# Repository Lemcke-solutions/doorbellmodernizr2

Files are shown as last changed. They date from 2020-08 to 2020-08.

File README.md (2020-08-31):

Imgur

This repository contains sample code and eagle/gerber/STL files for the Doorbell Modernizr 2 that is for sale on tindie: https://www.tindie.com/products/ErikLemcke/doorbell-modernizr-2/

The Doorbell Modernizr is a device that can transform your ordinary doorbell (running on 8 - 24v ac) into a "smart" wifi doorbell.
Whenever someone presses your doorbell, the Doorbell Modernizr can send a signal to your home automation system (currently supported: Home assistant, Domoticz and Openhab).
With the doorbell modernizr 2 it is also possible to turn your doorbell on and off from your home automation system.

If you want to program the device yourself (for example with the Arduino IDE), you can do so by connecting it via USB to your computer.

I use the folowing settings for programming:

- Board: Generic EP8266 module
- Flash mode: QIO
- Flash size: 512K (64K SPIFFS)
- Debugging port: Disabled
- Debug level: None
- IwIP variant: V2 lower memory
- reset method: ck
- crystal frequency: 26Mhz
- Flash frequency: 40Mhz
- CPU frequency: 80Mhz
- Builtin led: 2
- Upload speed: 115200
- Erase flash: Only sketch

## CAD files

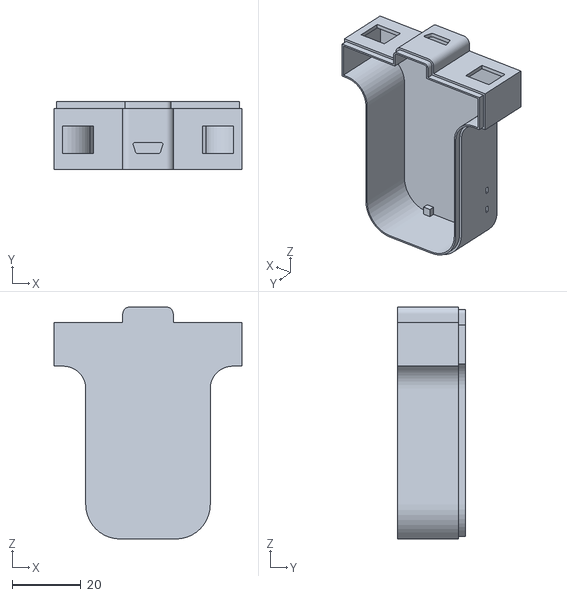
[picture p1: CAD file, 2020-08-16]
3d files/botom.STL
54.6 x 19.7 x 67.4

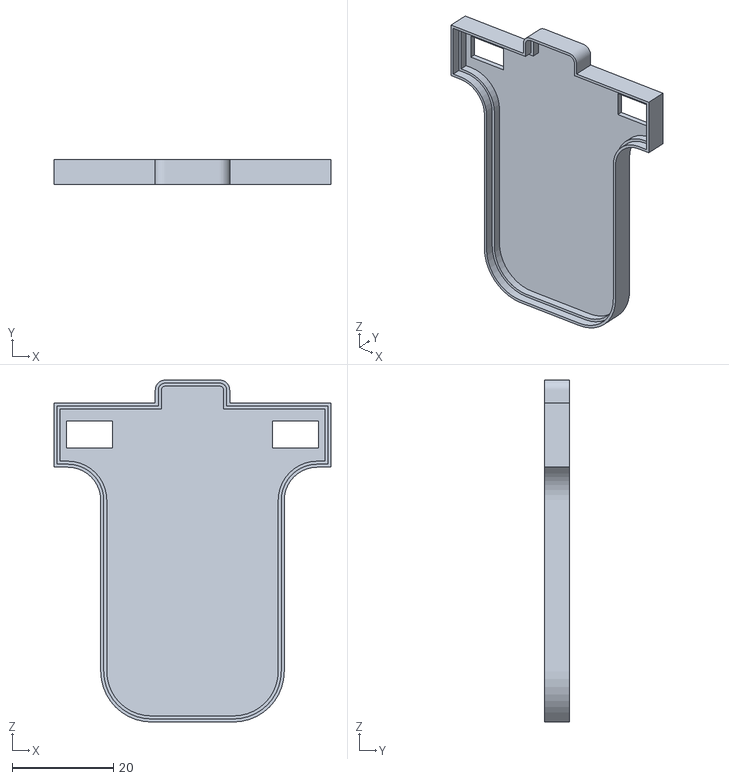
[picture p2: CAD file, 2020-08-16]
3d files/top.STL
54.6 x 5.00 x 67.4

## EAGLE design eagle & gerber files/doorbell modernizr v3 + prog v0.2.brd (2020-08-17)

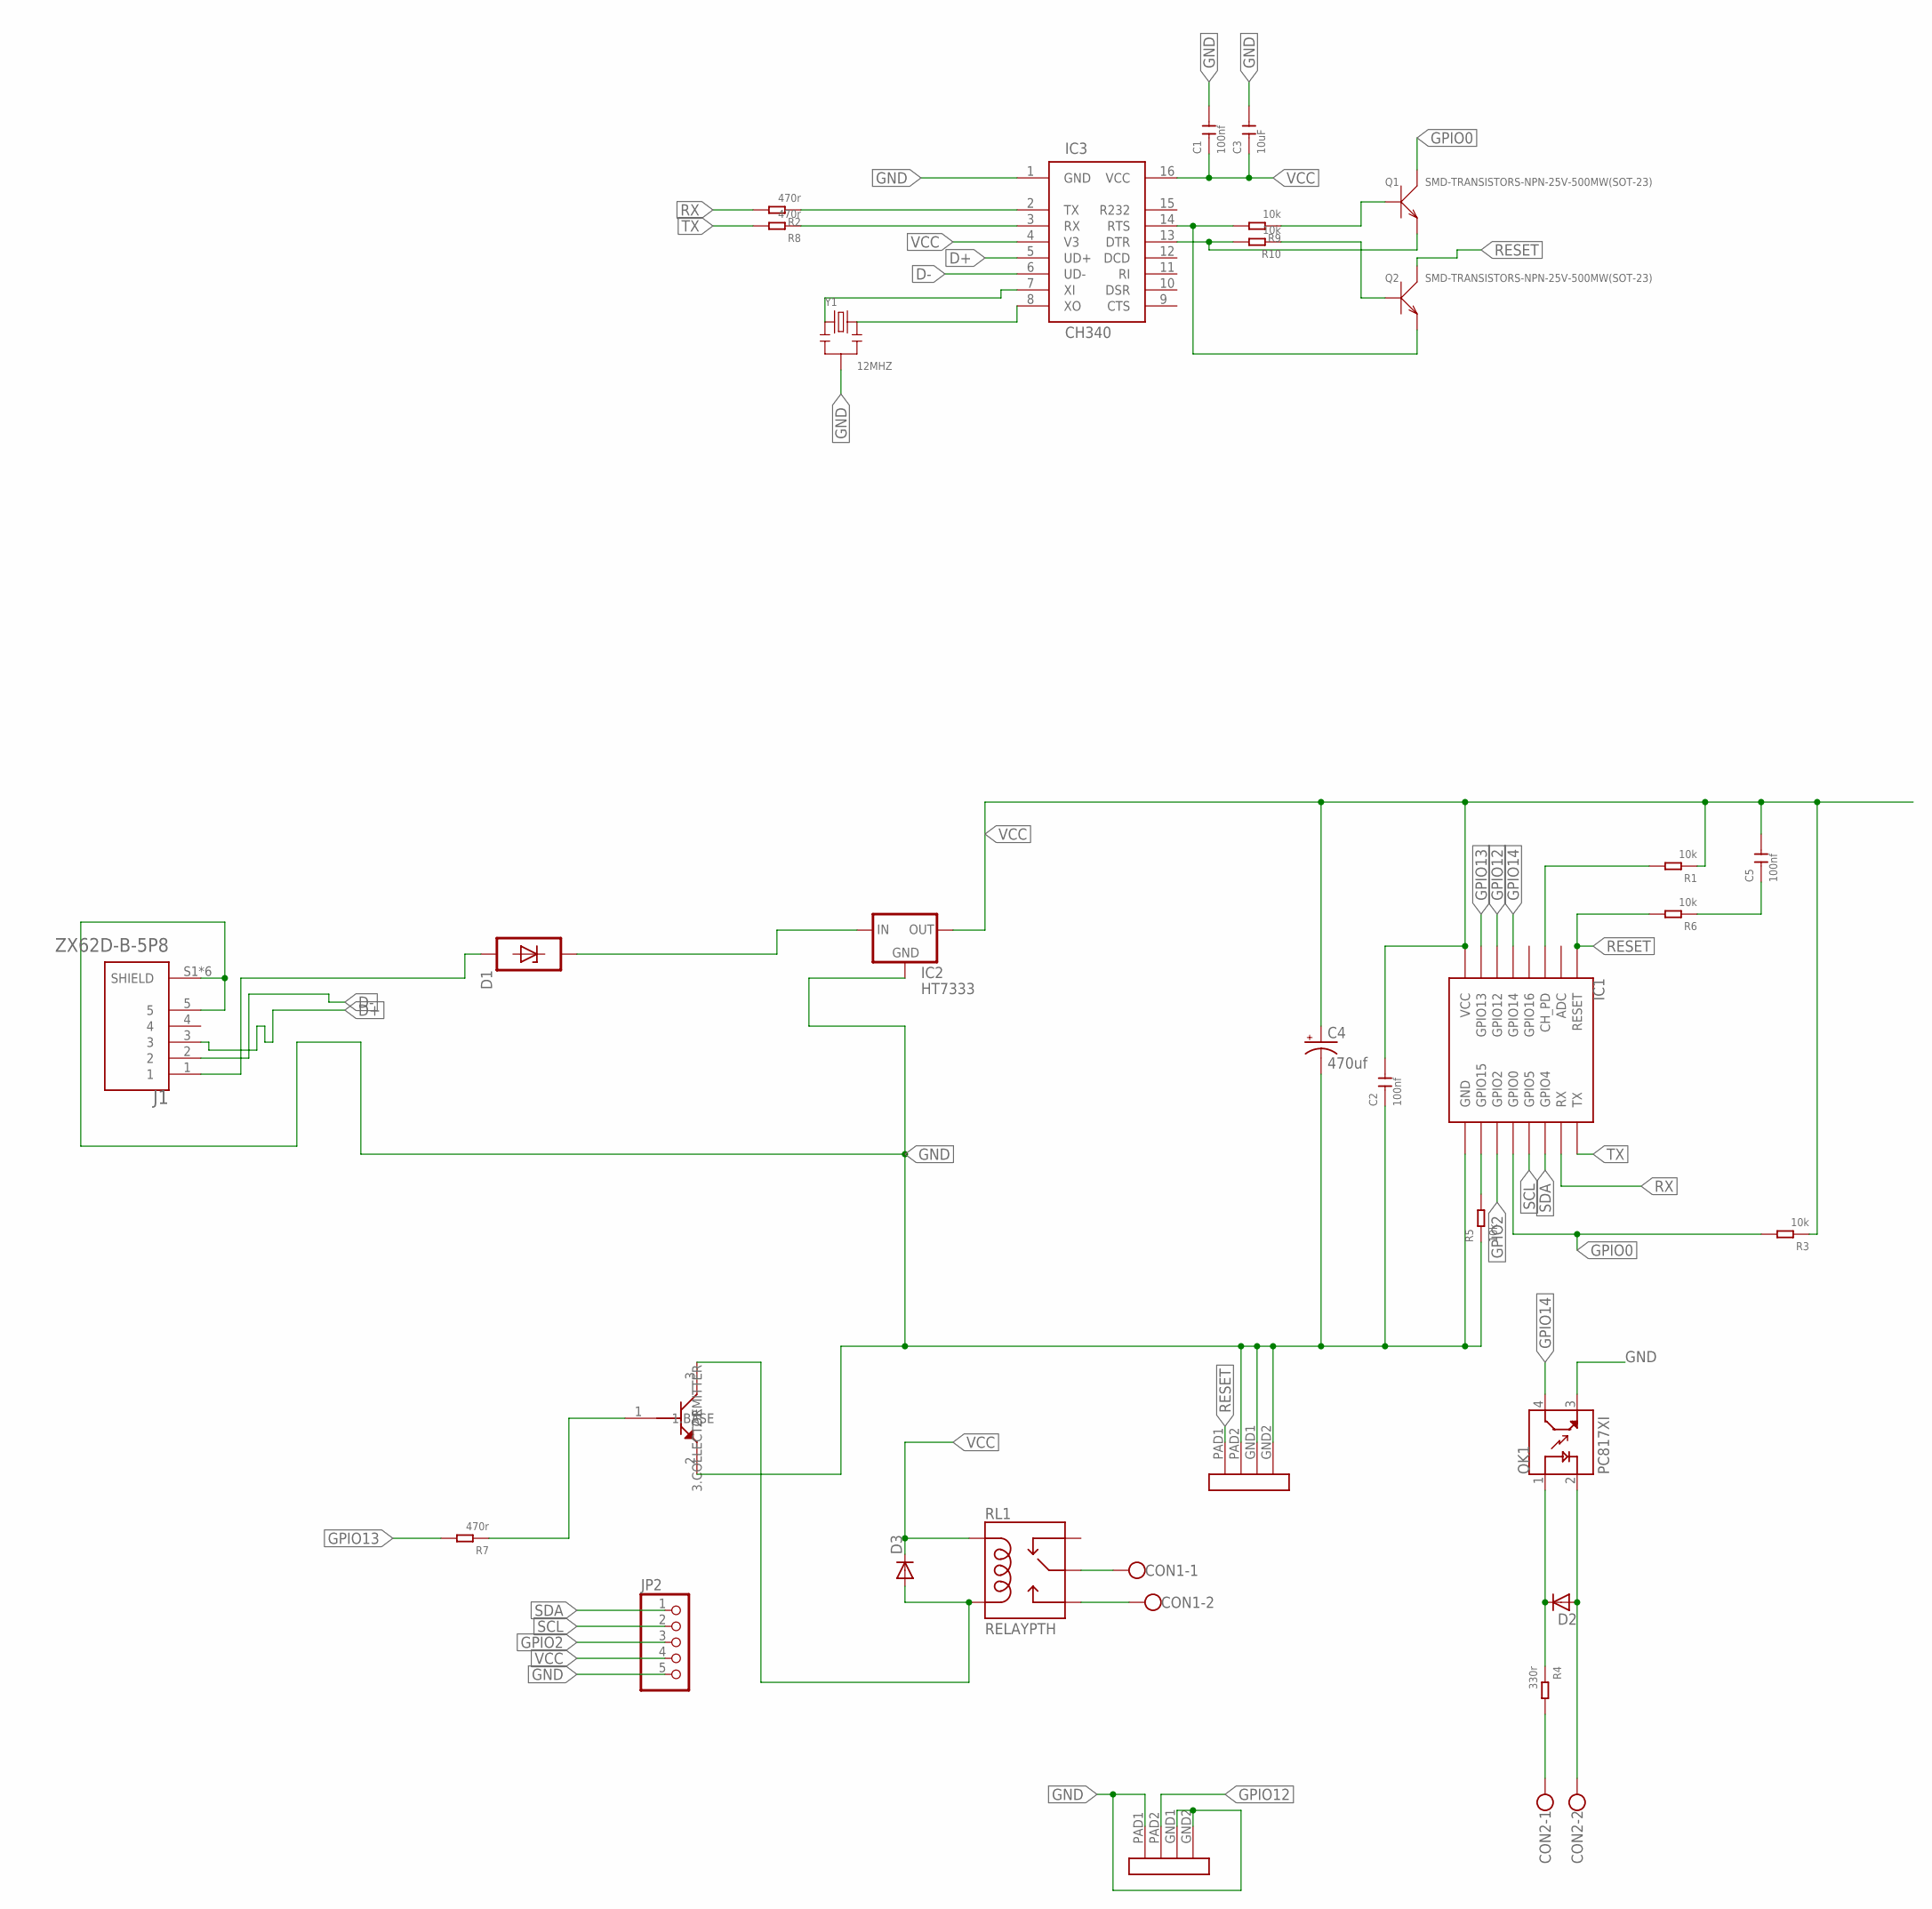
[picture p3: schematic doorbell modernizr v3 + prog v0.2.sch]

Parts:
C1, C2, C5: 100nf; C0603
C3: 10uF; C0603
C4: 470uf; PANASONIC_D
CON1, CON2: W237-102
D1: SP4020-01FTG; SOD323
D2: D-SOD123; SOD123
D3: DIODE-SOD123; SOD123
IC1: ESP12SMD; ESP12-SMD
IC2: HT7333; SOT-89
IC3: CH340; SOIC16
J1: ZX62D-B-5P8; HRS_ZX62D-B-5P8
JP2: PINHD-1X5; 1X05
OK1: PC817XI; SOIC254P975X460-4N
Q1, Q2: SMD-TRANSISTORS-NPN-25V-500MW(SOT-23); SOT-23
Q3: 2N2222; SOT23
R1, R3, R5, R6, R9, R10: 10k; R0603
R2, R7, R8: 470r; R0603
R4: 330r; R0603
RL1: RELAYPTH; SRD-05VDC-SL-C
SW1, SW2: MINI-SIDE-SWITCH
Y1: 12MHZ; X3-SMD-3.6X1.3X0.8MM

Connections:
D+: IC3.5 (UD+), J1.3
D-: IC3.6 (UD-), J1.2
GND: C1.2, C2.1, C3.2, C4.-, IC1.GND, IC2.2 (GND), IC3.1 (GND), J1.5, J1.S1 (SHIELD), J1.S2 (SHIELD), J1.S3 (SHIELD), J1.S4 (SHIELD), J1.S5 (SHIELD), J1.S6 (SHIELD), JP2.5, OK1.3 (ET), Q3.2 (2.EMITTER), R5.1, SW1.GND1, SW1.GND2, SW1.PAD2, SW2.GND1, SW2.GND2, SW2.PAD1, Y1.2
GPIO0: IC1.GPIO0, Q1.3 (C), R3.2
GPIO2: IC1.GPIO2, JP2.3
GPIO12: IC1.GPIO12, SW2.PAD2
GPIO13: IC1.GPIO13, R7.2
GPIO14: IC1.GPIO14, OK1.4 (CT)
unnamed: IC1.GPIO15, R5.2
unnamed: D3.A, Q3.3 (3.COLLECTOR), RL1.COIL0
unnamed: D2.1 (C), OK1.1 (A), R4.1
unnamed: CON2.2, D2.2 (A), OK1.2 (C)
unnamed: IC1.CH_PD, R1.2
unnamed: CON2.1, R4.2
unnamed: CON1.2, RL1.SWOPEN
unnamed: IC3.2 (TX), R2.1
unnamed: D1.1, IC2.4 (IN), IC2.P$2 (IN)
unnamed: CON1.1, RL1.SWCOMMON
unnamed: IC3.3 (RX), R8.1
unnamed: Q3.1 (1.BASE), R7.1
unnamed: IC3.14 (RTS), Q2.2 (E), R9.2
unnamed: IC3.13 (DTR), Q1.2 (E), R10.2
unnamed: Q1.1 (B), R9.1
unnamed: Q2.1 (B), R10.1
unnamed: IC3.8 (XO), Y1.3
unnamed: IC3.7 (XI), Y1.1
unnamed: D1.2, J1.1
unnamed: C5.1, R6.1
RESET: IC1.RESET, Q2.3 (C), R6.2, SW1.PAD1
RX: IC1.RXD0 (RX), R2.2
SCL: IC1.GPIO5, JP2.2
SDA: IC1.GPIO4, JP2.1
TX: IC1.TXD0 (TX), R8.2
VCC: C1.1, C2.2, C3.1, C4.+, C5.2, D3.C, IC1.VCC, IC2.1 (OUT), IC3.4 (V3), IC3.16 (VCC), JP2.4, R1.1, R3.1, RL1.COIL1

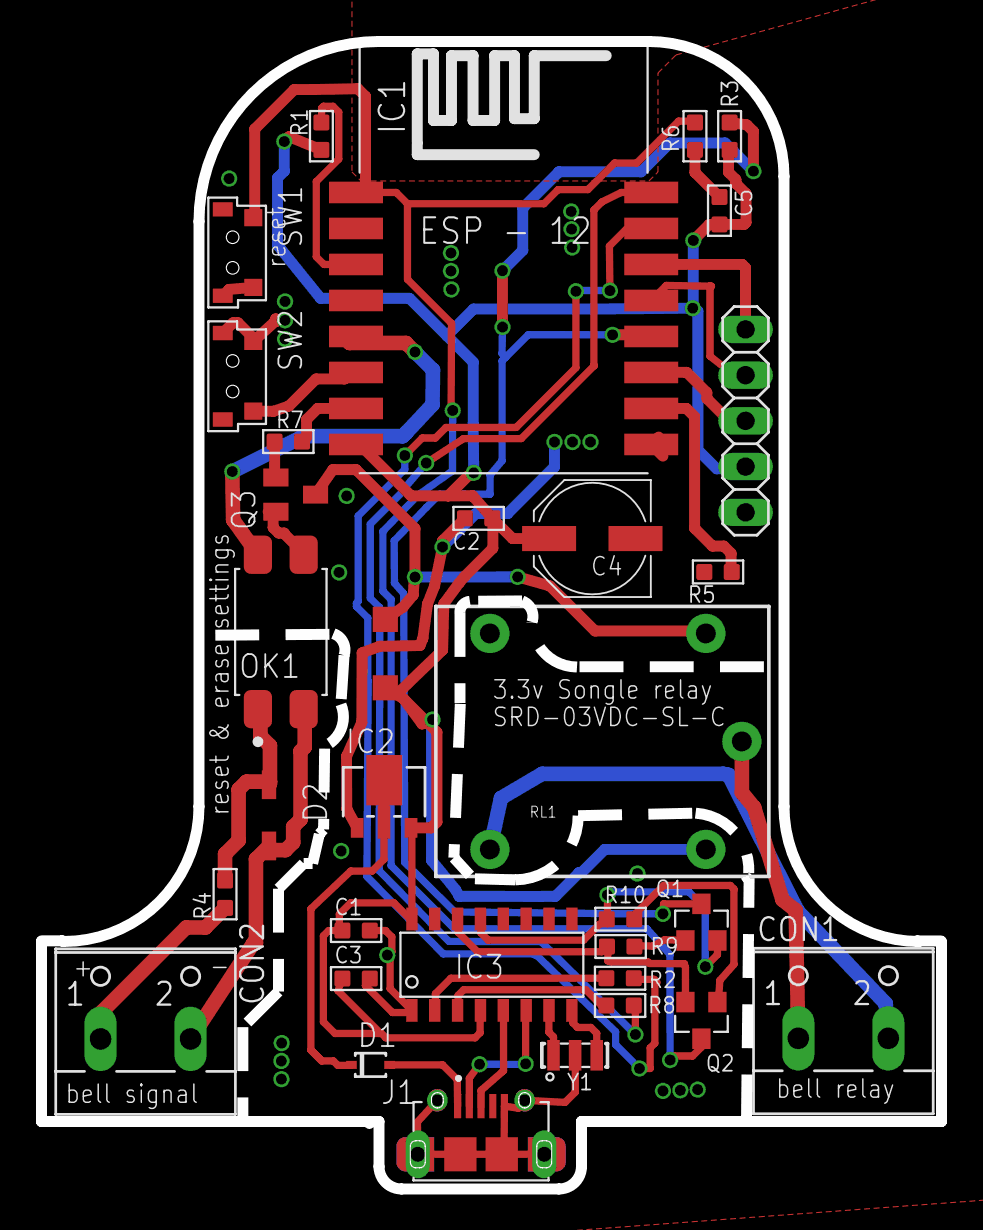
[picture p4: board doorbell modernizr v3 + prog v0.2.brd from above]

Board: 2 copper layers, 50.0 x 63.8 mm, 33 parts (0 on the bottom side), 34 nets.

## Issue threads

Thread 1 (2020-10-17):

Foute link op tindie page

Tristan79, 2020-10-17:
He! Ik zat alvast naar de source code te kijken en de handleiding op github maar ik zat naar het verkeerde te kijken.
Er staat een foute link in de beschrijving...

https://www.tindie.com/products/ErikLemcke/doorbell-modernizr-2/#product-description

Deze sectie:

**Open source**
The Doorbell Modernizr is open source, you can find the Arduino source code, STL files for the housing and gerber files for the board on [github](https://github.com/eriknl1982/mqtt_doorbell)

https://github.com/eriknl1982/mqtt_doorbell was niet de goede link :-) Ik raakte al verward.

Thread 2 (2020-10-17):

Question about

Tristan79, 2020-10-17:
Helaas ben ik niet zo goed in electronica,... en ik zat te brainstormen, waaruit een paar vragen rollen.

---
Hoe bevestig je het aan de muur?

Zitten er gaten aan de onderkant van de 3d print, en zo niet als ik er gaten in boor, zit er dan gennoeg ruimte tussen de pcb en de onderkant van het kastje? En dan de schroeven afdekken met tape lijkt mij. Of is er een andere manier? Lijkt me niet handig om dit los in de meterkast te hangen namelijk.

---

Als ik de belknop uit de groene circuit haal. De rest hetzelfde laat, en dan via de gpio pinnen van de esp de deurbel druk detecteerd.

Heb ik dan niet een situatie? Waar:

- Als nadeel dat als er geen stroom zit op de modernizr de bel het niet doet. Wat me geen ramp lijkt.
- De modernizr zelf de bel via de relais aan en uit zal moeten zetten als de belknop ingedrukt word.
- Dat als de belknop ingedrukt wordt, het dan altijd gedetecteerd kan worden. Ongeacht of de bel wel of niet ingeschakeld wordt met de relais.
- Het blauwe circuit kan gebruiken om te detecteren, dat als iemand op de bel drukt en de bel gaat niet af terwijl de relais wel is ingezet.  _Omdat iemand weer aan het aan en uit knopje heeft gezeten van de trafo zelf, om rust te hebben. Wat soms gebeurt (en ze vergeten ut altijd terug te zetten)._ Zie [trafo](https://www.123groepenkast.nl/Files/10/222000/222295/ProductPhotos/MaxContent/1154318476.jpg) ik mezelf daar een melding van kan geven dat de trafo uitstaat.
- Code moet kloppen om het hierboven geschetste scenario te realiseren.

In welke stand staat de relay als de modernizr op de stroom aangesloten word.

---
Na aanleiding van http://www.olino.org/blog/nl/articles/2009/08/31/de-standaard-deurbel-en-zijn-verspilling/

Als ik de relay gebruik om de stroom te onderbreken niet in het 8v ac circuit maar voor de transformator in het 230v ac circuit. Kan dat met deze hardware? Niet echt dat ik dat van plan was. Ik vind klooien in de meterkast al eng genoeg.

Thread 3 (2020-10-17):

Firmware Blob Missing

Tristan79, 2020-10-17:
There is no firmware blob, in the repository.
Would be nice to have the original bin file in case everything goes wrong.

Tristan79, 2020-10-17:
I could not flash any sketch onto it until I downgraded "ESP8266 Boards" to version 2.5.2

v2.7.4, not working (esptool.FatalError: Timed out waiting for packet header)
v2.6.3, not working (esptool.FatalError: Timed out waiting for packet header)

Tested it on a couple of computers running macos and windows... It just is not working.

**Software, board and libraries used**
- OSX Sierra/Arduino 1.8.13
- ESP8266 Boards" to version 2.5.2
- WifiManager 0.15.0
- ArduinoJSON 5.13.5 (>6 not working)
- PubSubClient 2.8.0

Now it works 👍

Note: Macos catalina does not communicate correctly in Arduino with the serial devices (apple fault :-)
Took me 4 hours just to get it to flash 👎

Tristan79, 2020-10-19:
Got v2.7.4 working. I accidentally left the board on WeMoS D1 R1 on a random computer. It uploaded the sketch on just worked.

Change
> no dtr (ck)

to

> dtr (aka nodemcu)

It made flashin' with esp8266 boards bigger then 2.5.2 great again.

This also means, that you manual should update your README.md (and your manual). Such that people like me don't get stuck for hours :-)

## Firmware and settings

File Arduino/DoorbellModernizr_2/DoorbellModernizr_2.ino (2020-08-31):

/***************************************************************************
 Code to use with doorbell, modernizr2 , see https://www.tindie.com/products/ErikLemcke/mqtt--wifi-doorbell-with-esp8266/
 Created by Erik Lemcke 12-05-2020


 This code can be used from the arduino library, you will need the following libraries:
 https://github.com/tzapu/WiFiManager     Included in this repository (src folder)
 https://github.com/bblanchon/ArduinoJson
 https://github.com/knolleary/pubsubclient
 https://github.com/esp8266/Arduino/tree/master/libraries/ESP8266mDNS

 credits:

 https://tzapu.com/                   for the awesome WiFiManger library
 https://github.com/esp8266/Arduino   fopr the ESP8266 arduino core
 https://arduinojson.org/             for the ArduinoJson library
 https://pubsubclient.knolleary.net/  for the mqtt library
  
 ***************************************************************************/
#include <fs.h>                   //this needs to be first, or it all crashes and burns...
#import "index.h"

#include <ESP8266WiFi.h>          //https://github.com/esp8266/Arduino

//needed for library
#include <DNSServer.h>
#include <ESP8266WebServer.h>
#include "src/WiFiManager.h" 

#include <ArduinoJson.h>          //https://github.com/bblanchon/ArduinoJson
#include <PubSubClient.h>
#include <base64.h>
#include <ESP8266HTTPClient.h>

int doorbellState = 0;
int resetState = 0;
const int doorbellPin = 14;

WiFiClient espClient;
HTTPClient http; 
PubSubClient client(espClient);

WiFiManager wifiManager;
ESP8266WebServer server(80);

unsigned long previousMillis = 0;       

DNSServer dnsServer; //Needed for captive portal when device is already connected to a wifi network

//extra parameters
char mqtt_server[40];
char mqtt_port[6] ;
char mqtt_username[40];
char mqtt_password[40];
char mqtt_topic[40];
char mqtt_switch_topic[47];
char mqtt_status_topic[47];
char mqtt_status[60] = "unknown";

char dz_idx[5];
char oh_itemid[40];

//flag for saving data
bool shouldSaveConfig = false;
bool apstarted = false;

//callback notifying us of the need to save config
void saveConfigCallback () {
  Serial.println("Should save config");
  shouldSaveConfig = true;
}

void configModeCallback (WiFiManager *myWiFiManager) {
  Serial.println("Connection to previous set wifi failed. Erasing settings before becoming AP");
  //SPIFFS.format(); 
}


//Handle webserver root request
void handleRoot() {
  Serial.println("Config page is requested");
  String addy = server.client().remoteIP().toString();
  
  //determine if this user is connected to the AP or comming from the network the device is connected to
  //when connected to AP, configuration is not allowed
  if (addy == "192.168.4.2"){
      server.send(200, "text/html", "The doorbell modernizr can be configured on address http:// " + WiFi.localIP().toString() + " when connected to wifi network " + WiFi.SSID());
  } else {
    String configPage = FPSTR(config_page);
    configPage.replace("{v}", "Doorbell modernizr configuration");
    configPage.replace("{1}", mqtt_server);
    configPage.replace("{2}", mqtt_port);
    configPage.replace("{3}", mqtt_username);
    configPage.replace("{4}", mqtt_password);
    configPage.replace("{5}", mqtt_topic);
    configPage.replace("{6}", mqtt_status);
    configPage.replace("{7}", dz_idx);
    configPage.replace("{8}", oh_itemid);
    
    server.send(200, "text/html", configPage);
  }
}

void saveSettings() {
  Serial.println("Handling webserver request savesettings");

  //store the updates values in the json config file
    DynamicJsonBuffer jsonBuffer;
    JsonObject& json = jsonBuffer.createObject();
    json["mqtt_server"] = server.arg("mqtt_server");
    json["mqtt_port"] = server.arg("mqtt_port");
    json["mqtt_username"] = server.arg("mqtt_username");
    json["mqtt_password"] = server.arg("mqtt_password");
    json["mqtt_topic"] = server.arg("mqtt_topic");

    json["dz_idx"] = server.arg("dz_idx");
    json["oh_itemid"] = server.arg("oh_itemid");
   
    File configFile = SPIFFS.open("/config.json", "w");
    if (!configFile) {
      Serial.println("failed to open config file for writing");
    }

    json.printTo(Serial);
    json.printTo(configFile);
    configFile.close();

    //put updated parameters into memory so they become effective immediately
    server.arg("mqtt_server").toCharArray(mqtt_server,40);
    server.arg("mqtt_port").toCharArray(mqtt_port,40);
    server.arg("mqtt_username").toCharArray(mqtt_username,40);
    server.arg("mqtt_password").toCharArray(mqtt_password,40);
    server.arg("mqtt_topic").toCharArray(mqtt_topic,40);
    server.arg("dz_idx").toCharArray(dz_idx,40);
    server.arg("oh_itemid").toCharArray(oh_itemid,40);
   
    server.send(200, "text/html", "Settings have been saved. You will be redirected to the configuration page in 5 seconds <meta http-equiv=\"refresh\" content=\"5; url=/\" />");
    
    //mqtt settings might have changed, let's reconnect to the mqtt server if one is configured
    if (strlen(mqtt_topic) != 0){
      Serial.println("mqtt topic set, need to connect");
      reconnect();
    }
}

void handleOn(){
  digitalWrite(13, LOW);
  digitalWrite(2, LOW);
  Serial.println("turning doorbell on");
  if(client.connected()){
     client.publish(mqtt_status_topic, "ON" , true);
  }
  server.send(200);
}

void handleOff(){
  digitalWrite(13, HIGH);
  digitalWrite(2, HIGH);
  Serial.println("turning doorbell off"); 
  if(client.connected()){
     client.publish(mqtt_status_topic, "OFF" , true);
  }
  server.send(200);
}


void handleIncommingMqttMessages(char* topic, byte* payload, unsigned int length) {
  strcpy(mqtt_status_topic, mqtt_topic);
  strcat(mqtt_status_topic, "_status");    
  
  String Message = "";
  
  for (int i = 0; i < length; i++) {
    Message += (char)payload[i];
  }

  if (Message == "ON"){
    handleOn();
  }

  if (Message == "OFF"){
    handleOff();
  }
}

void setup() {
 
  Serial.begin(115200);
  Serial.println();
  Serial.println("Doorbell modernizr 2");
  Serial.println("Firmware version 1.0");

  pinMode(doorbellPin, INPUT_PULLUP);
  pinMode(12, INPUT_PULLUP);
  pinMode(LED_BUILTIN, OUTPUT);
  pinMode(13, OUTPUT); //relay
  pinMode(2, OUTPUT); //led
 
  //read configuration from FS json
  Serial.println("mounting file system");

  if (SPIFFS.begin()) {
    Serial.println("mounted file system");
    if (SPIFFS.exists("/config.json")) {
      //file exists, reading and loading
      Serial.println("reading config file");
      File configFile = SPIFFS.open("/config.json", "r");
      if (configFile) {
        Serial.println("opened config file");
        size_t size = configFile.size();
        // Allocate a buffer to store contents of the file.
        std::unique_ptr<char[]> buf(new char[size]);

        configFile.readBytes(buf.get(), size);
        DynamicJsonBuffer jsonBuffer;
        JsonObject& json = jsonBuffer.parseObject(buf.get());
        if (json.success()) {
          Serial.println("parsed config file json");

          strcpy(mqtt_server, json["mqtt_server"]);
          strcpy(mqtt_port, json["mqtt_port"]);
          strcpy(mqtt_username, json["mqtt_username"]);
          strcpy(mqtt_password, json["mqtt_password"]);
          strcpy(mqtt_topic, json["mqtt_topic"]);

          strcpy(dz_idx, json["dz_idx"]);
          strcpy(oh_itemid, json["oh_itemid"]);

        } else {
          Serial.println("failed to load json config");
        }
      }
    }
  } else {
    Serial.println("failed to mount file system");
  }
  //end read

  WiFiManagerParameter custom_mqtt_server("server", "ip address", mqtt_server, 40);
  WiFiManagerParameter custom_mqtt_port("port", "port", mqtt_port, 5);
  WiFiManagerParameter custom_mqtt_username("username", "username", mqtt_username, 40);
  WiFiManagerParameter custom_mqtt_password("password", "password", mqtt_password, 40);
  WiFiManagerParameter custom_mqtt_topic("topic", "mqtt topic", mqtt_topic, 40);

  WiFiManagerParameter custom_dz_idx("dzidx", "Domoticz idx", dz_idx, 5);
  WiFiManagerParameter custom_oh_itemid("ohitemid", "OpenHAB itemId", oh_itemid, 40);

  WiFiManagerParameter custom_text("<p>Fill the folowing values with your home assistant/ domoticz infromation. Username and password are optional</p>");
  wifiManager.addParameter(&custom_text);

  //set config save notify callback
  wifiManager.setSaveConfigCallback(saveConfigCallback);

  wifiManager.setAPCallback(configModeCallback);

  wifiManager.addParameter(&custom_mqtt_server);
  wifiManager.addParameter(&custom_mqtt_port);
  wifiManager.addParameter(&custom_mqtt_username);
  wifiManager.addParameter(&custom_mqtt_password);

  WiFiManagerParameter custom_text1("<p>Fill the folowing field with your MQTT topic for Home assistant</p>");
  wifiManager.addParameter(&custom_text1);
  
  wifiManager.addParameter(&custom_mqtt_topic);

  WiFiManagerParameter custom_text2("<p>Fill the folowing field with your IDX value for Domoticz</p>");
  wifiManager.addParameter(&custom_text2);
    
  wifiManager.addParameter(&custom_dz_idx);

  WiFiManagerParameter custom_text3("<p>Fill the folowing field with your itemId for OpenHAB</p>");
  wifiManager.addParameter(&custom_text3);

  wifiManager.addParameter(&custom_oh_itemid);

  //fetches ssid and pass and tries to connect
  //if it does not connect it starts an access point with the specified name
  //and goes into a blocking loop awaiting configuration  
    
  if (!wifiManager.autoConnect("Doorbell modernizr")) {
    Serial.println("failed to connect and hit timeout");
    delay(3000);
    //reset and try again
    ESP.reset();
    delay(5000);
  }

  //if you get here you have connected to the WiFi
  Serial.println("connected to wifi network");

  //Define url's for webserver 
  server.on("/on", handleOn);
  server.on("/off", handleOff);
  server.on("/saveSettings", saveSettings);
  server.on("/", handleRoot);
  server.onNotFound([]() {
    handleRoot();
  });
  server.begin();

  //read updated parameters
  strcpy(mqtt_server, custom_mqtt_server.getValue());
  strcpy(mqtt_port, custom_mqtt_port.getValue());
  strcpy(mqtt_username, custom_mqtt_username.getValue());
  strcpy(mqtt_password, custom_mqtt_password.getValue());
  strcpy(mqtt_topic, custom_mqtt_topic.getValue());

  strcpy(dz_idx, custom_dz_idx.getValue());
  strcpy(oh_itemid, custom_oh_itemid.getValue());

  //save the custom parameters to FS
  if (shouldSaveConfig) {
    Serial.println("saving config");
    DynamicJsonBuffer jsonBuffer;
    JsonObject& json = jsonBuffer.createObject();
    json["mqtt_server"] = mqtt_server;
    json["mqtt_port"] = mqtt_port;
    json["mqtt_username"] = mqtt_username;
    json["mqtt_password"] = mqtt_password;
    json["mqtt_topic"] = mqtt_topic;
    json["dz_idx"] = dz_idx;
    json["oh_itemid"] = oh_itemid;

    File configFile = SPIFFS.open("/config.json", "w");
    if (!configFile) {
      Serial.println("failed to open config file for writing");
    }

    json.printTo(Serial);
    json.printTo(configFile);
    configFile.close();
    //end save
  }

  //MQTT
  client.setServer(mqtt_server, atoi(mqtt_port));
  client.setCallback(handleIncommingMqttMessages);

  Serial.println("Doorbell modernizr ip on " + WiFi.SSID() + ": " + WiFi.localIP().toString());
  client.publish(mqtt_status_topic, "ON" , true);
 
}


//MQTT reconnect function
void reconnect() {
  client.disconnect();
  client.setServer(mqtt_server, atoi(mqtt_port));
  Serial.print("Attempting MQTT connection to ");
  Serial.print(mqtt_server);
  Serial.print(" on port ");
  Serial.print(mqtt_port);
  Serial.print("...");
  
  if (client.connect("DoorbellModernizr_2", mqtt_username, mqtt_password)) {
     Serial.println("connected");
     String("<div style=\"color:green;float:left\">connected</div>").toCharArray(mqtt_status,60);
     Serial.print("sending 'off' message to ");
     Serial.print(mqtt_server);
     Serial.print(" on port ");
     Serial.print(mqtt_port);
     Serial.print(" with topic ");
     Serial.println(mqtt_topic);
     client.publish(mqtt_topic, "off" , true);

     strcpy(mqtt_switch_topic, mqtt_topic);
     strcat(mqtt_switch_topic, "_switch");    
     client.subscribe(mqtt_switch_topic);
   } else {
     Serial.print("failed, rc=");
     String("<div style=\"color:red;float:left\">connection failed</div>").toCharArray(mqtt_status,60);
     Serial.print(client.state());
     Serial.println(" try again in 5 seconds");

  

    unsigned long previousMillis1 = 0;

     //connection failed, Go into a (non-blocking) loop until we are connected 
     while (!client.connected()) {
        resetstate();
         server.handleClient();  //call to handle webserver connection needed, because the while loop will block the processor
         unsigned long currentMillis1 = millis();
         if(currentMillis1 - previousMillis1 >= 5000) {
         previousMillis1 = currentMillis1;
         Serial.print("Attempting MQTT connection...");
          if (client.connect("Doorbellmodernizr2", mqtt_username, mqtt_password)) {
                Serial.println("connected");
                String("<div style=\"color:green;float:left\">connected</div>").toCharArray(mqtt_status,60);
             } else {
                     String("<div style=\"color:red;float:left\">connection failed</div>").toCharArray(mqtt_status,60);
                Serial.print("failed, rc=");
                Serial.print(client.state());
                Serial.println(" try again in 5 seconds");
             }
         }
      }
   }
}

long lastMsg = 0;

//Initialize a reset if pin 12 is low
void resetstate (){
   resetState = digitalRead(12);
   if (resetState == LOW){
    Serial.println("It seems someone wants to go for a reset...");
  
    int count = 0;

    //Flash the led for 5 seconds
    while (count < 25 && digitalRead(12) == LOW) {
      digitalWrite(LED_BUILTIN, HIGH);   
      delay(100);                      
      digitalWrite(LED_BUILTIN, LOW);    
      delay(100);                      
      count ++;
    }
  
    resetState = digitalRead(12);
    //See if they still want to go for it
    if (resetState == LOW){
       Serial.println("Let's do it");
       SPIFFS.format();
       wifiManager.resetSettings();
       delay(500);
       ESP.restart();  
    } else {
      Serial.println("They chickened out...");
      Serial.println("Starting AP that can be used to obtain IP");

      boolean result = false;
      while (result == false){
        result = WiFi.softAP("Doorbell modernizr online" );  
      }
      
      if(result == true)
      {
        dnsServer.start(53, "*", WiFi.softAPIP());
          
        apstarted = true;
        previousMillis =  millis();
        Serial.println("AP IP address: " +  WiFi.softAPIP().toString());
      }
    }
  }
}


void loop() {

  //if a AP is started, kill it after 3 minutes
  if (apstarted == true){
    unsigned long currentMillis = millis();
    if (currentMillis - previousMillis >= 300000) {
      previousMillis = currentMillis;
      Serial.println("Stopping the AP, 3 minutes are past!");
      WiFi.softAPdisconnect(false);
      apstarted = false;    
    }
  }
 
  resetstate();
  
  if (strlen(mqtt_topic) != 0){
     //try to reconnect to mqtt server if connection is lost
    if (!client.connected()) { 
      reconnect();
    }
    client.loop();
  }
  
  server.handleClient();
  dnsServer.processNextRequest();
   
  doorbellState = digitalRead(doorbellPin);
  resetState = digitalRead(12);
    
 if ( doorbellState == LOW ) {
  
    if (strlen(mqtt_topic) != 0){
      client.publish(mqtt_topic, "on" , true);
      Serial.print("Doorbell is pressed!, sending 'on' message to ");
      Serial.print(mqtt_server);
      Serial.print(" on port ");
      Serial.print(mqtt_port);
      Serial.print(" with topic ");
      Serial.println(mqtt_topic);
      
  
      //wait 5 seconds, then publish the off message
      delay( 5000 );
  
      
      Serial.print("sending 'off' message to ");
      Serial.print(mqtt_server);
      Serial.print(" on port ");
      Serial.print(mqtt_port);
      Serial.print(" with topic ");
      Serial.println(mqtt_topic);
      client.publish(mqtt_topic, "off" , true);    
    }
   if (strlen(dz_idx) != 0){
    if (espClient.connect(mqtt_server,atoi(mqtt_port))){
      Serial.println("sending 'on' message to Domiticz");
      espClient.print("GET /json.htm?type=command&param=udevice&idx=");
      espClient.print(String(dz_idx));
      espClient.print("&nvalue=1");
      
      if (strlen(mqtt_username) != 0){
        espClient.print("&username=");
        espClient.print(base64::encode(mqtt_username));
        espClient.print("&password=");
        espClient.print(base64::encode(mqtt_password));
      }
      
      espClient.println(" HTTP/1.1");
      espClient.print("Host: ");
      espClient.print(String(mqtt_server));
      espClient.print(":");
      espClient.println(String(mqtt_port));
      espClient.println("User-Agent: doorbell-modernizr");
      espClient.println("Connection: close");
      espClient.println();
      espClient.stop();
   } else {
     Serial.println("connect failed");
   }
      //wait 5 seconds, then publish the off message
      delay( 5000 );
    if (espClient.connect(mqtt_server,atoi(mqtt_port))){
        Serial.println("sending 'off' message to Domiticz");
        espClient.print("GET /json.htm?type=command&param=udevice&idx=");
        espClient.print(String(dz_idx));
        espClient.print("&nvalue=0");
  
         if (strlen(mqtt_username) != 0){
          espClient.print("&username=");
          espClient.print(base64::encode(mqtt_username));
          espClient.print("&password=");
          espClient.print(base64::encode(mqtt_password));
        }
        
        espClient.println(" HTTP/1.1");
        espClient.print("Host: ");
        espClient.print(String(mqtt_server));
        espClient.print(":");
        espClient.println(String(mqtt_port));
        espClient.println("User-Agent: doorbell-modernizr");
        espClient.println("Connection: close");
        espClient.println();
        espClient.stop();
     } else {
       Serial.println("connect failed");
     } 
   }

   // OpenHAB
   if (strlen(oh_itemid) != 0){
      Serial.println("sending 'ON' message to openHAB");
      http.begin("http://" + String(mqtt_server) + ":" + String(mqtt_port) +"/rest/items/" + String(oh_itemid)); 
      http.POST("ON");
      http.end();

      delay(5000);

      Serial.println("sending 'OFF' message to openHAB");
      http.begin("http://" + String(mqtt_server) + ":" + String(mqtt_port) +"/rest/items/" + String(oh_itemid)); 
      http.POST("OFF"); 
      http.end();
    
   }  
  }
}

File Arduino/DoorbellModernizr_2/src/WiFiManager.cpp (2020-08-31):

/**************************************************************
   WiFiManager is a library for the ESP8266/Arduino platform
   (https://github.com/esp8266/Arduino) to enable easy
   configuration and reconfiguration of WiFi credentials using a Captive Portal
   inspired by:
   http://www.esp8266.com/viewtopic.php?f=29&t=2520
   https://github.com/chriscook8/esp-arduino-apboot
   https://github.com/esp8266/Arduino/tree/esp8266/hardware/esp8266com/esp8266/libraries/DNSServer/examples/CaptivePortalAdvanced
   Built by AlexT https://github.com/tzapu
   Licensed under MIT license
 **************************************************************/

#include "WiFiManager.h"

WiFiManagerParameter::WiFiManagerParameter(const char *custom) {
  _id = NULL;
  _placeholder = NULL;
  _length = 0;
  _value = NULL;

  _customHTML = custom;
}

WiFiManagerParameter::WiFiManagerParameter(const char *id, const char *placeholder, const char *defaultValue, int length) {
  init(id, placeholder, defaultValue, length, "");
}

WiFiManagerParameter::WiFiManagerParameter(const char *id, const char *placeholder, const char *defaultValue, int length, const char *custom) {
  init(id, placeholder, defaultValue, length, custom);
}

void WiFiManagerParameter::init(const char *id, const char *placeholder, const char *defaultValue, int length, const char *custom) {
  _id = id;
  _placeholder = placeholder;
  _length = length;
  _value = new char[length + 1];
  for (int i = 0; i < length; i++) {
    _value[i] = 0;
  }
  if (defaultValue != NULL) {
    strncpy(_value, defaultValue, length);
  }

  _customHTML = custom;
}

const char* WiFiManagerParameter::getValue() {
  return _value;
}
const char* WiFiManagerParameter::getID() {
  return _id;
}
const char* WiFiManagerParameter::getPlaceholder() {
  return _placeholder;
}
int WiFiManagerParameter::getValueLength() {
  return _length;
}
const char* WiFiManagerParameter::getCustomHTML() {
  return _customHTML;
}

WiFiManager::WiFiManager() {
}

void WiFiManager::addParameter(WiFiManagerParameter *p) {
  _params[_paramsCount] = p;
  _paramsCount++;
  DEBUG_WM("Adding parameter");
  DEBUG_WM(p->getID());
}

void WiFiManager::setupConfigPortal() {
  dnsServer.reset(new DNSServer());
  server.reset(new ESP8266WebServer(80));

  DEBUG_WM(F(""));
  _configPortalStart = millis();

  DEBUG_WM(F("Configuring access point... "));
  DEBUG_WM(_apName);
  if (_apPassword != NULL) {
    if (strlen(_apPassword) < 8 || strlen(_apPassword) > 63) {
      // fail passphrase to short or long!
      DEBUG_WM(F("Invalid AccessPoint password. Ignoring"));
      _apPassword = NULL;
    }
    DEBUG_WM(_apPassword);
  }

  //optional soft ip config
  if (_ap_static_ip) {
    DEBUG_WM(F("Custom AP IP/GW/Subnet"));
    WiFi.softAPConfig(_ap_static_ip, _ap_static_gw, _ap_static_sn);
  }

  if (_apPassword != NULL) {
    WiFi.softAP(_apName, _apPassword);//password option
  } else {
    WiFi.softAP(_apName);
  }

  delay(500); // Without delay I've seen the IP address blank
  DEBUG_WM(F("AP IP address: "));
  DEBUG_WM(WiFi.softAPIP());

  /* Setup the DNS server redirecting all the domains to the apIP */
  dnsServer->setErrorReplyCode(DNSReplyCode::NoError);
  dnsServer->start(DNS_PORT, "*", WiFi.softAPIP());

  /* Setup web pages: root, wifi config pages, SO captive portal detectors and not found. */
  server->on("/", std::bind(&WiFiManager::handleRoot, this));
  server->on("/wifi", std::bind(&WiFiManager::handleWifi, this, true));
  server->on("/0wifi", std::bind(&WiFiManager::handleWifi, this, false));
  server->on("/wifisave", std::bind(&WiFiManager::handleWifiSave, this));
  server->on("/i", std::bind(&WiFiManager::handleInfo, this));
  server->on("/r", std::bind(&WiFiManager::handleReset, this));
  //server->on("/generate_204", std::bind(&WiFiManager::handle204, this));  //Android/Chrome OS captive portal check.
  server->on("/fwlink", std::bind(&WiFiManager::handleRoot, this));  //Microsoft captive portal. Maybe not needed. Might be handled by notFound handler.
  server->onNotFound (std::bind(&WiFiManager::handleNotFound, this));
  server->begin(); // Web server start
  DEBUG_WM(F("HTTP server started"));

}

boolean WiFiManager::autoConnect() {
  String ssid = "ESP" + String(ESP.getChipId());
  return autoConnect(ssid.c_str(), NULL);
}

boolean WiFiManager::autoConnect(char const *apName, char const *apPassword) {
  DEBUG_WM(F(""));
  DEBUG_WM(F("AutoConnect"));

  // read eeprom for ssid and pass
  //String ssid = getSSID();
  //String pass = getPassword();

  // attempt to connect; should it fail, fall back to AP
  WiFi.mode(WIFI_STA);

  if (connectWifi("", "") == WL_CONNECTED)   {
    DEBUG_WM(F("IP Address:"));
    DEBUG_WM(WiFi.localIP());
    //connected
    return true;
  }

  return startConfigPortal(apName, apPassword);
}

boolean  WiFiManager::startConfigPortal(char const *apName, char const *apPassword) {
  //setup AP
  WiFi.mode(WIFI_AP_STA);
  DEBUG_WM("SET AP STA");

  _apName = apName;
  _apPassword = apPassword;

  //notify we entered AP mode
  if ( _apcallback != NULL) {
    _apcallback(this);
  }

  connect = false;
  setupConfigPortal();

  while (_configPortalTimeout == 0 || millis() < _configPortalStart + _configPortalTimeout) {
    //DNS
    dnsServer->processNextRequest();
    //HTTP
    server->handleClient();


    if (connect) {
      connect = false;
      delay(2000);
      DEBUG_WM(F("Connecting to new AP"));

      // using user-provided  _ssid, _pass in place of system-stored ssid and pass
      if (connectWifi(_ssid, _pass) != WL_CONNECTED) {
        DEBUG_WM(F("Failed to connect."));
      } else {
        //connected
        WiFi.mode(WIFI_STA);
        //notify that configuration has changed and any optional parameters should be saved
        if ( _savecallback != NULL) {
          //todo: check if any custom parameters actually exist, and check if they really changed maybe
          _savecallback();
        }
        break;
      }

      if (_shouldBreakAfterConfig) {
        //flag set to exit after config after trying to connect
        //notify that configuration has changed and any optional parameters should be saved
        if ( _savecallback != NULL) {
          //todo: check if any custom parameters actually exist, and check if they really changed maybe
          _savecallback();
        }
        break;
      }
    }
    yield();
  }

  server.reset();
  dnsServer.reset();

  return  WiFi.status() == WL_CONNECTED;
}
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

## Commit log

2020-08-16 arduino files
2020-08-16 manual & 3d files
    [botom.STL, top.STL]
2020-08-17 eagle and gerber files
    [doorbell modernizr v3 + prog v0.2.GBL, doorbell modernizr v3 + prog v0.2.GBO, doorbell modernizr v3 + prog v0.2.GBP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]

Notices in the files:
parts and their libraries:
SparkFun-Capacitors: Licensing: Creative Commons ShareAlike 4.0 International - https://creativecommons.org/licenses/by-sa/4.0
